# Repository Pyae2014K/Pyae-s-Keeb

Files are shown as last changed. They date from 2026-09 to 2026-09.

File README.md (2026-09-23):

# Pyae-s-Keeb

My Keeb is a 75% keyboard with a knob and via support.
The firmware was built with QMK.

It serves as a keyboard that I can use every day to type and play games.

## Features:
- EC11 Rotary Encoder for Volume
- 82 Switches for the keys
- [VIA](https://www.caniusevia.com/) support

## PCB
My PCB was made in KiCad.

Schematic



PCB



I used [Joe Scotto's](https://www.youtube.com/@joe_scotto) footprints for most of the components.

## CAD Model
Everyting fits together using 8 M3 Screws and Heatset inserts.

It has 2 different pieces, the Case



and the Plate



## Firmware
This Keeb uses [QMK](https://qmk.fm/) firmware for the code.
-82 Switches for keys
-Rotary encoder for volume

## Bom:
Here is everything needed to make my Keeb

82x Cherry MX Switches
82x DSA Keycaps
8x M3x5x4 Heatset inserts
8x M3x18mm SHCS Bolts
83x 1N4148 DO-35 Diodes.
1x EC11 Rotary Encoder
1x Raspberry Pi Pico
1x Case (2 printed parts)

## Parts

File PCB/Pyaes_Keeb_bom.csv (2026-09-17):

Designator | Footprint | Quantity | Value | LCSC Part #
A1 | RaspberryPi_Pico_Common_THT | 1 | RaspberryPi_Pico
D1, D10, D11, D12, D13, D14, D15, D16, D17, D18, D19, D2, D20, D21, D22, D23, D24, D25, D26, D27, D28, D29, D3, D30, D31, D32, D33, D34, D35, D36, D37, D38, D39, D4, D40, D41, D42, D43, D44, D45, D46, D47, D48, D49, D5, D50, D51, D52, D53, D54, D55, D56, D57, D58, D59, D6, D60, D61, D62, D63, D64, D65, D66, D67, D68, D69, D7, D70, D71, D72, D73, D74, D75, D76, D77, D78, D79, D8, D80, D81, D82, D83, D9 | D_DO-35_SOD27_P7.62mm_Horizontal | 83 | ~
S1, S10, S11, S12, S13, S14, S15, S16, S17, S18, S19, S2, S20, S21, S22, S23, S24, S25, S26, S27, S28, S3, S30, S32, S33, S34, S35, S36, S37, S38, S39, S4, S40, S41, S42, S43, S45, S47, S48, S49, S5, S50, S51, S52, S53, S54, S55, S56, S57, S58, S6, S60, S62, S63, S64, S65, S66, S67, S68, S69, S7, S70, S71, S72, S74, S75, S8, S80, S81, S82, S83, S84, S85, S86, S9 | MX_PCB_1.00u | 75 | ~
S29 | STAB_MX_2u | 1 | MX_stab
S31, S44 | MX_PCB_1.50u | 2 | ~
S46, S73 | MX_PCB_1.75u | 2 | ~
S59, S61 | STAB_MX_2.25u | 2 | MX_stab
S76, S77, S78 | MX_PCB_1.25u | 3 | ~
S79 | STAB_MX_6.25u | 1 | MX_stab
SW1 | Encoder_EC11_MX | 1 | RotaryEncoder_Switch

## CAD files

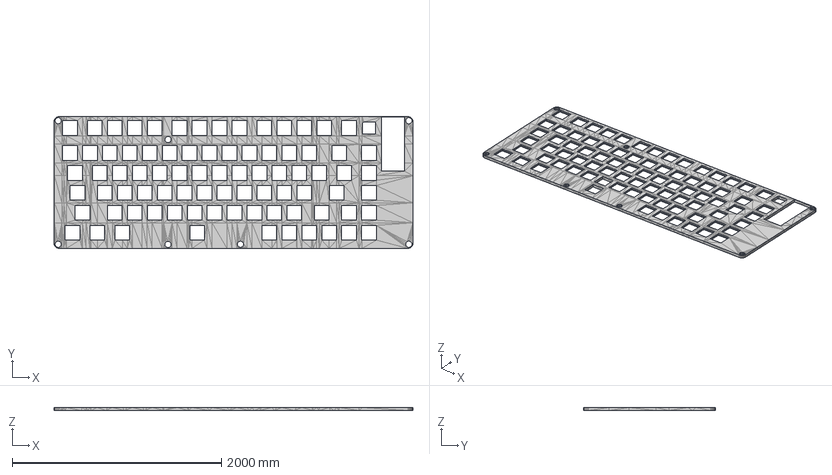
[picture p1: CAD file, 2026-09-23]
CAD/Pyae's Keeb (Plate).step
3429.5 x 1259.5 x 30.0 mm

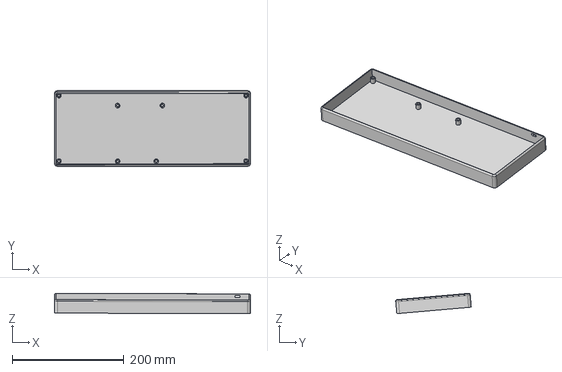
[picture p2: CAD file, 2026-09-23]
CAD/Pyae's Keeb (Case).step
351.1 x 135.5 x 36.3 mm

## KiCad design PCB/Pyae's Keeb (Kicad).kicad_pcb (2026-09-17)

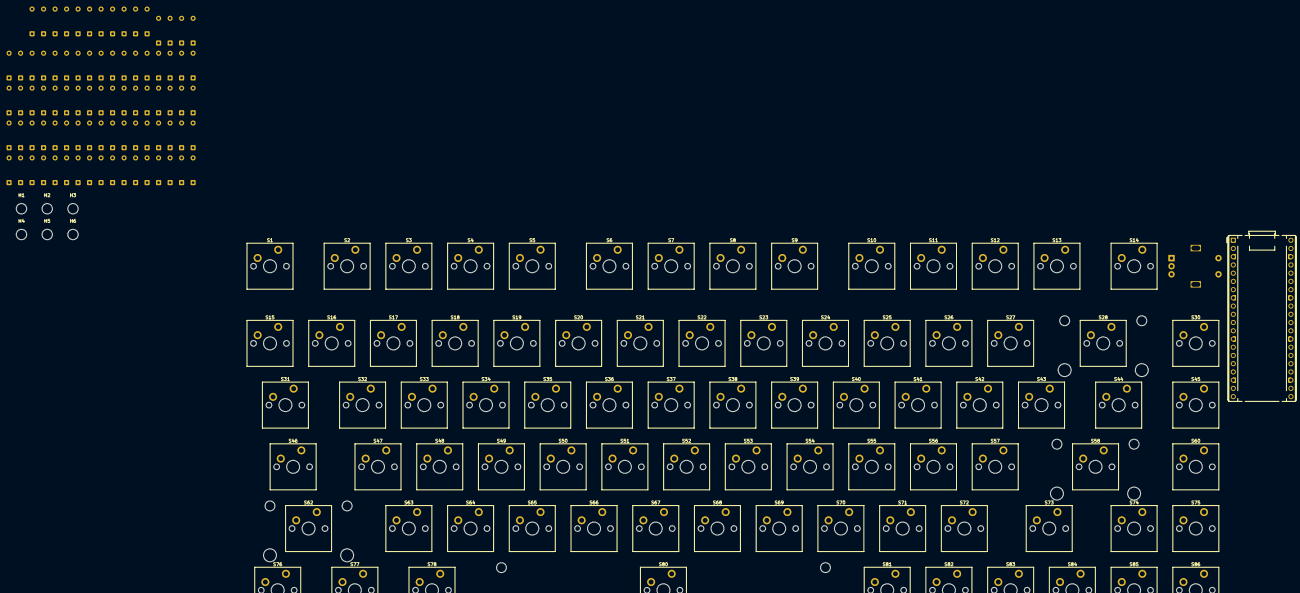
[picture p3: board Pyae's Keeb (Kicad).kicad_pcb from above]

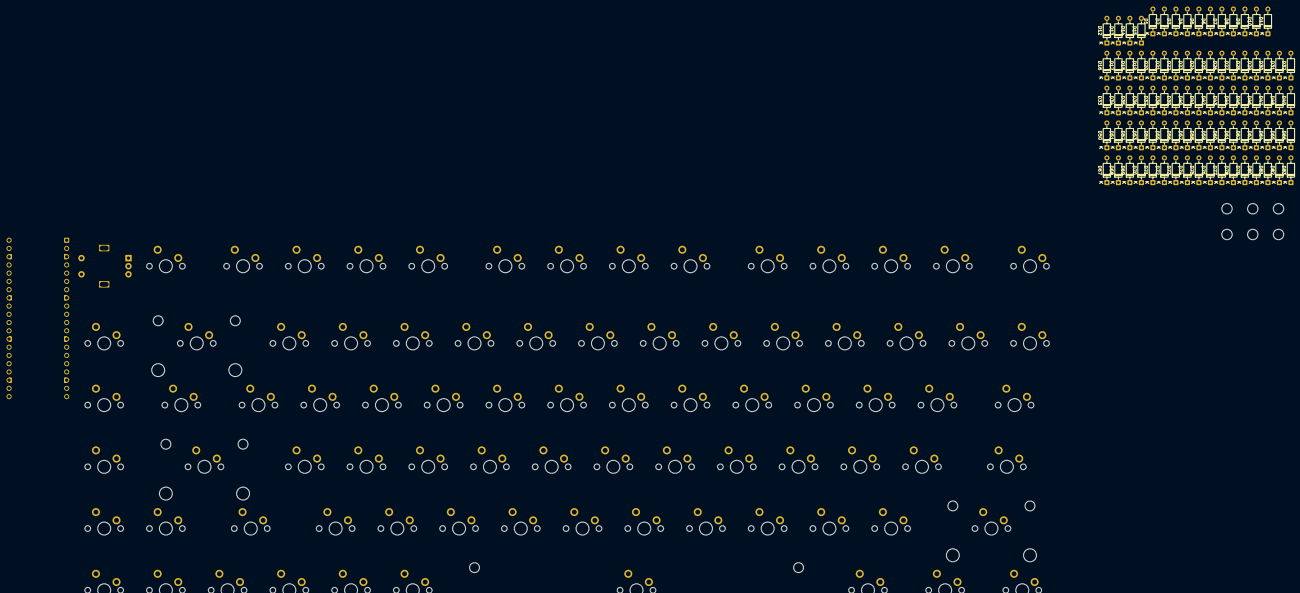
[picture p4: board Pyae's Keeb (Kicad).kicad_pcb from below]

Board: 2 copper layers, 177 parts (83 on the bottom side), 107 nets, no tracks yet.

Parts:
A1: RaspberryPi_Pico; RaspberryPi_Pico_Common_THT
D1, D2, D3, D4, D5, D6, D7, D8, D9, D10, D11, D12, D13, D14, D15, D16, D17, D18, D19, D20, D21, D22, D23, D24, D25, D26, D27, D28, D29, D30, D31, D32, D33, D34, D35, D36, D37, D38, D39, D40, D41, D42, D43, D44, D45, D46, D47, D48, D49, D50, D51, D52, D53, D54, D55, D56, D57, D58, D59, D60, D61, D62, D63, D64, D65, D66, D67, D68, D69, D70, D71, D72, D73, D74, D75, D76, D77, D78, D79, D80, D81, D82, D83: D_DO-35_SOD27_P7.62mm_Horizontal
H1, H2, H3, H4, H5, H6: MountingHole; MountingHole_3.2mm_M3
S1, S2, S3, S4, S5, S6, S7, S8, S9, S10, S11, S12, S13, S14, S15, S16, S17, S18, S19, S20, S21, S22, S23, S24, S25, S26, S27, S28, S30, S32, S33, S34, S35, S36, S37, S38, S39, S40, S41, S42, S43, S45, S47, S48, S49, S50, S51, S52, S53, S54, S55, S56, S57, S58, S60, S62, S63, S64, S65, S66, S67, S68, S69, S70, S71, S72, S74, S75, S80, S81, S82, S83, S84, S85, S86: MX_PCB_1.00u
S29: MX_stab; STAB_MX_2u
S31, S44: MX_PCB_1.50u
S46, S73: MX_PCB_1.75u
S59, S61: MX_stab; STAB_MX_2.25u
S76, S77, S78: MX_PCB_1.25u
S79: MX_stab; STAB_MX_6.25u
SW1: RotaryEncoder_Switch; Encoder_EC11_MX

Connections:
Col0: A1.1 (GPIO0), S1.1, S15.1, S31.1, S46.1, S62.1, S76.1
Col1: A1.2 (GPIO1), S2.1, S16.1, S32.1, S47.1, S63.1, S77.1
Col2: A1.4 (GPIO2), S3.1, S17.1, S33.1, S48.1, S64.1, S78.1
Col3: A1.5 (GPIO3), S4.1, S18.1, S34.1, S49.1, S65.1
Col4: A1.6 (GPIO4), S5.1, S19.1, S35.1, S50.1, S66.1
Col5: A1.7 (GPIO5), S6.1, S20.1, S36.1, S51.1, S67.1, S80.1
Col6: A1.9 (GPIO6), S7.1, S21.1, S37.1, S52.1, S68.1
Col7: A1.10 (GPIO7), S8.1, S22.1, S38.1, S53.1, S69.1
Col8: A1.11 (GPIO8), S9.1, S23.1, S39.1, S54.1, S70.1, S81.1
Col9: A1.12 (GPIO9), S10.1, S24.1, S40.1, S55.1, S71.1, S82.1
Col10: A1.14 (GPIO10), S11.1, S25.1, S41.1, S56.1, S72.1, S83.1
Col11: A1.15 (GPIO11), S12.1, S26.1, S42.1, S57.1, S73.1, S84.1
Col12: A1.16 (GPIO12), S13.1, S27.1, S43.1, S58.1, S74.1, S85.1
Col13: A1.17 (GPIO13), S14.1, S28.1, S44.1
Col14: A1.19 (GPIO14), S30.1, S45.1, S60.1, S75.1, S86.1, SW1.S1
GND: A1.3 (GND), A1.8 (GND), A1.13 (GND), A1.18 (GND), A1.23 (GND), A1.28 (GND), A1.38 (GND), SW1.C
unnamed: D67.2 (A), S1.2
unnamed: D68.2 (A), S15.2
unnamed: D69.2 (A), S31.2
unnamed: D70.2 (A), S46.2
unnamed: D71.2 (A), S62.2
unnamed: D72.2 (A), S76.2
unnamed: D73.2 (A), S2.2
unnamed: D74.2 (A), S16.2
unnamed: D75.2 (A), S32.2
unnamed: D76.2 (A), S47.2
unnamed: D77.2 (A), S63.2
unnamed: D78.2 (A), S77.2
unnamed: D79.2 (A), S3.2
unnamed: D80.2 (A), S17.2
unnamed: D81.2 (A), S33.2
unnamed: D82.2 (A), S48.2
unnamed: D83.2 (A), S64.2
unnamed: D50.2 (A), S78.2
unnamed: D51.2 (A), S4.2
unnamed: D52.2 (A), S18.2
unnamed: D53.2 (A), S34.2
unnamed: D54.2 (A), S49.2
unnamed: D55.2 (A), S65.2
unnamed: D56.2 (A), S5.2
unnamed: D57.2 (A), S19.2
unnamed: D58.2 (A), S35.2
unnamed: D59.2 (A), S50.2
unnamed: D60.2 (A), S66.2
unnamed: D61.2 (A), S6.2
unnamed: D62.2 (A), S20.2
unnamed: D63.2 (A), S36.2
unnamed: D64.2 (A), S51.2
unnamed: D65.2 (A), S67.2
unnamed: D66.2 (A), S80.2
unnamed: D33.2 (A), S7.2
unnamed: D34.2 (A), S21.2
unnamed: D35.2 (A), S37.2
unnamed: D36.2 (A), S52.2
unnamed: D37.2 (A), S68.2
unnamed: D38.2 (A), S8.2
unnamed: D39.2 (A), S22.2
unnamed: D40.2 (A), S38.2
unnamed: D41.2 (A), S53.2
unnamed: D42.2 (A), S69.2
unnamed: D43.2 (A), S9.2
unnamed: D44.2 (A), S23.2
unnamed: D45.2 (A), S39.2
unnamed: D46.2 (A), S54.2
unnamed: D47.2 (A), S70.2
unnamed: D48.2 (A), S81.2
unnamed: D49.2 (A), S10.2
unnamed: D16.2 (A), S24.2
unnamed: D17.2 (A), S40.2
unnamed: D18.2 (A), S55.2
unnamed: D19.2 (A), S71.2
unnamed: D20.2 (A), S82.2
unnamed: D21.2 (A), S11.2
unnamed: D22.2 (A), S25.2
unnamed: D23.2 (A), S41.2
unnamed: D24.2 (A), S56.2
unnamed: D25.2 (A), S72.2
unnamed: D26.2 (A), S83.2
unnamed: D27.2 (A), S12.2
unnamed: D28.2 (A), S26.2
unnamed: D29.2 (A), S42.2
unnamed: D30.2 (A), S57.2
unnamed: D31.2 (A), S73.2
unnamed: D32.2 (A), S84.2
unnamed: D12.2 (A), S13.2
unnamed: D13.2 (A), S27.2
unnamed: D14.2 (A), S43.2
unnamed: D15.2 (A), S58.2
unnamed: D1.2 (A), S74.2
unnamed: D2.2 (A), S85.2
unnamed: D3.2 (A), S14.2
unnamed: D4.2 (A), S28.2
unnamed: D5.2 (A), S44.2
unnamed: D7.2 (A), S30.2
unnamed: D8.2 (A), S45.2
unnamed: D9.2 (A), S60.2
unnamed: D10.2 (A), S75.2
unnamed: D11.2 (A), S86.2
Row0: A1.21 (GPIO16), D3.1 (K), D6.1 (K), D12.1 (K), D21.1 (K), D27.1 (K), D33.1 (K), D38.1 (K), D43.1 (K), D49.1 (K), D51.1 (K), D56.1 (K), D61.1 (K), D67.1 (K), D73.1 (K), D79.1 (K)
Row1: A1.22 (GPIO17), D4.1 (K), D7.1 (K), D13.1 (K), D16.1 (K), D22.1 (K), D28.1 (K), D34.1 (K), D39.1 (K), D44.1 (K), D52.1 (K), D57.1 (K), D62.1 (K), D68.1 (K), D74.1 (K), D80.1 (K)
Row2: A1.24 (GPIO18), D5.1 (K), D8.1 (K), D14.1 (K), D17.1 (K), D23.1 (K), D29.1 (K), D35.1 (K), D40.1 (K), D45.1 (K), D53.1 (K), D58.1 (K), D63.1 (K), D69.1 (K), D75.1 (K), D81.1 (K)
Row3: A1.25 (GPIO19), D9.1 (K), D15.1 (K), D18.1 (K), D24.1 (K), D30.1 (K), D36.1 (K), D41.1 (K), D46.1 (K), D54.1 (K), D59.1 (K), D64.1 (K), D70.1 (K), D76.1 (K), D82.1 (K)
Row4: A1.26 (GPIO20), D1.1 (K), D10.1 (K), D19.1 (K), D25.1 (K), D31.1 (K), D37.1 (K), D42.1 (K), D47.1 (K), D55.1 (K), D60.1 (K), D65.1 (K), D71.1 (K), D77.1 (K), D83.1 (K)
Row5: A1.27 (GPIO21), D2.1 (K), D11.1 (K), D20.1 (K), D26.1 (K), D32.1 (K), D48.1 (K), D50.1 (K), D66.1 (K), D72.1 (K), D78.1 (K)
SwB: D6.2 (A), SW1.S2
TnA: A1.20 (GPIO15), SW1.A
TnB: A1.29 (GPIO22), SW1.B

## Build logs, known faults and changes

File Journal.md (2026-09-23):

# Journal

## The PCB
  I made the brain of my keyboard, the PCB, and it was really challenging because
I only knew how to make a small macropad so this was way more than what I have 
done before but after some time I finally got it to work out.

The PCB I made



## CAD
  Making the Case and Plate of my keyboard was very frustrating because I kind of 
suck at 3D modeling and also because am used to Shapr 3D and it can't export STEP 
files unless I pay money for a subscription :c. Well after a lot of crying and a 
sleep less day I finally finished it.

The Case and Plate




## Firmware
  The firmware was not as bad as the case and plate because it is not really different 
from programing the Hackpad so I had some experience no making it.
